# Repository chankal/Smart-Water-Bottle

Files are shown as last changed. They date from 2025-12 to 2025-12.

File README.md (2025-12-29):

# Smart-Water-Bottle
Water bottle attachment 

Hardware: 
- ESP32 s3 reverse feather with tft display
- MPU 6050
- DS3231 RTC
- HX711 Load Cell Amplifier + Load Cell Sensor

Proper hydration is important for many bodily functions and prevents dehydration which can lead to further complications. My smart bottle attachment can attach to any bottle and track hydration levels by keeping track of how often you drink water and how much water you drink. The user will be able to view this information on a web dashboard and tft display to clearly view their trends. Many people tend to forget about drinking water as it gets pushed to the back of their mind. I hope this device will allow people to be more mindful of staying hydrated

I originally experimented with using capacitance to read water level but later pivoted to using a load cell for more reliable results.

I made this project as part of CS 3651 Prototyping Intelligent Devices
[Project documentation (3).pdf](https://github.com/user-attachments/files/24356760/Project.documentation.3.pdf)

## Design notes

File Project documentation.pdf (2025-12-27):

## Smart Water Bottle Attachment Documentation:

Chandini Kalidindi

CS 3651

Goal/Motivation:

Proper hydration is important for many bodily functions and prevents dehydration which can lead to further complications. My smart bottle attachment can attach to any bottle and track hydration levels by keeping track of how often you drink water and how much water you drink. The user will be able to view this information on a dashboard to clearly see their trends. Many people tend to forget about drinking water as it gets pushed to the back of their mind. I hope this device will allow people to be more mindful of staying hydrated.

## Inputs:

For my microcontroller, I decided to use the ESP32-S3 with a tft display. This would allow the user to not have to charge the bottle as often since it uses less power than other microcontrollers and is able to do wifi connectivity so it can connect to my server to upload all drink information.

Weight(water level):
For my project, I needed a way to read water levels reliably over time. To do this I used a load cell which measures the weight of the water bottle. By calibrating to the empty weight and the full weight of the water bottle, I can correlate these values to the total capacity of water for the bottle. This means I will be able to measure how much water is in the bottle based on the weight.

Accelerometer:
In order to determine when an actual drink happens, I use the mpu 6050 to measure the acceleration along the z axis to approximate the tilt. When most of the acceleration is along the z axis that means it is upright. When assembling my project, I made sure that the mpu 6050 was mounted upward.

RTC: I used the rtc to log the time of the drink events to give the user a proper timeline of their hydration levels.

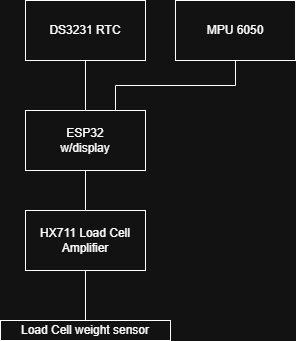
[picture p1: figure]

## Iterative Process:

Measuring Water Level:

For my project I originally wanted to use capacitance to measure water level by putting copper strips on the outside of the bottle. I originally tried using touchRead() to read capacitance but the values were too noisy and it was hard to measure any accurate values. I was able to get a slight linear relationship when pouring in water, but as soon as I moved the bottle slightly or brought my hand closer to the strips, it would mess up the values making it unusable.

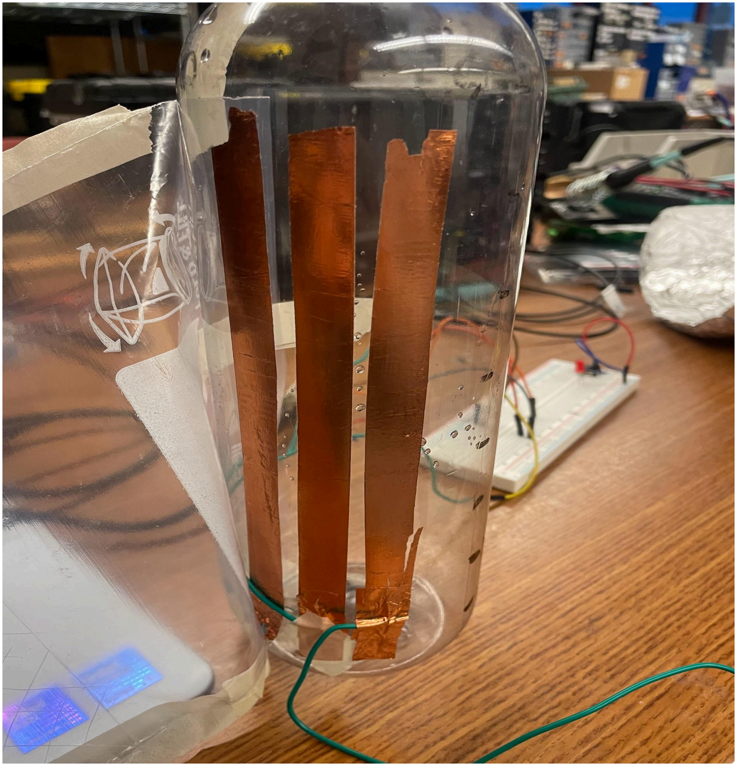
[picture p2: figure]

I also tried using a method similar to sd4 where I would take the amount of time it took the strips to charge based on the water level. The higher the water level, the longer the strips would charge before discharging. This method was a bit more promising after adding a grounded foil surrounding my bottle(not touching copper wires) and incorporating aggressive smoothing with the values. This method took a lot of experimenting with different resistor values to make the rc charging faster or slower. I also experimented with the size and placement of the copper strips. Overall after this process, I was able to detect changes in water level more reliably than my first method, but it still wasn’t reliable enough for long term measurements and the values would completely drift to different values. I believe this can be due to the changing humidity in the bottle and other environmental factors.

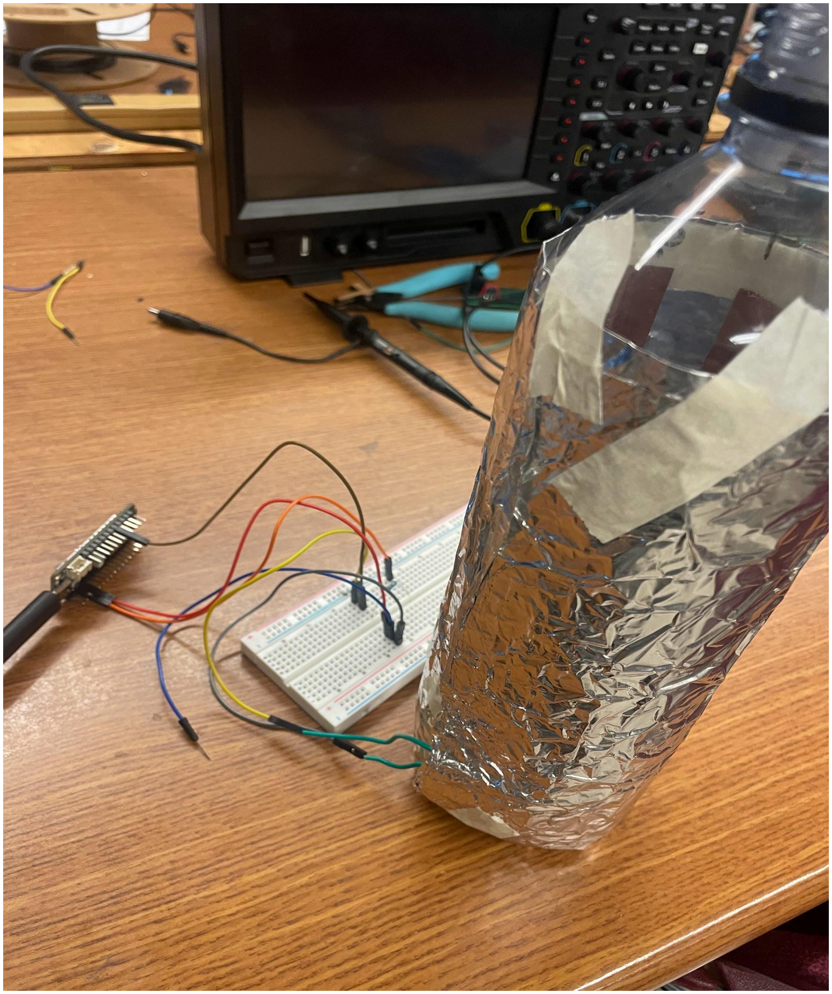
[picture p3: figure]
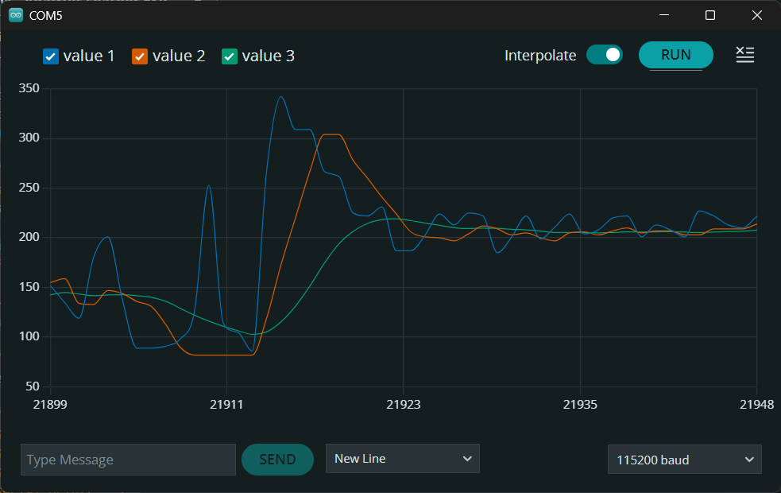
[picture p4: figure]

Overall, I concluded that using capacitance wouldn’t be a reliable way to measure water level for my project so I pivoted to my backup plan of using a load cell to measure weight which would be a much more reliable metric long term.

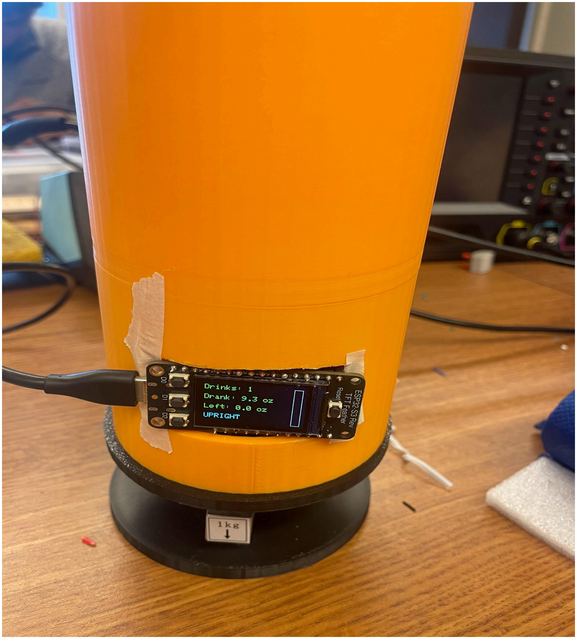
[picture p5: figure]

Outputs: For my outputs I used the tft display on the esp32. This allows me to stay more compact as I would not need additional hardware to mount on the outside of the bottle. On the tft display, the user can see how much water they have drank, how much they have left, and how many drinks they have to drink throughout the day. I also displayed this information on a hydration dashboard that the user can access to more easily view long term hydration information.

3D Printed Bottle Stand:

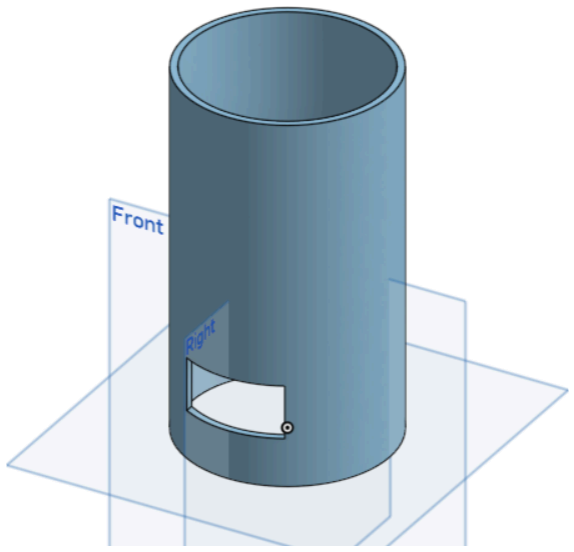
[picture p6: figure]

## Libraries:

Display:
Adafruit_GFX: I used this library for drawing text and shapes on my tft display Adafruit_ST7789: TFT Display driver

Sensors:
Adafruit_MPU6050: For accelerometer and gyro data.
Adafruit_Sensor
HX711: Library to read data from the load cell amplifier adc. RTClib: Library to interface with rtc using datetime.

Communication/data:
WiFi.h: Handles connecting the esp32 to wifi. HTTPClient.h: sends http post requests to fastapi backend. Fastapi
Pydantic
Sqlite3
Datetime

Esp32:
Wire.h : Handles i2c communication for the mpu6050 and rtc. SPI.h: Handles communication for tft display

## Resources:

DIY Capacitive Water Level Sensor using ESP32 Touch Read function (https://www.youtube.com/watch?v=40TjjWLljaU)

Non-contact Capacitive Liquid Level Sensing using FDC1004 - (https://www.hackster.io/team-protocentral/non-contact-capacitive-liquid-level-sensing-using-fdc1004-9333c7) Hackster.io

GitHub - Infineon/mtb-example-psoc4-capsense-liquid-level-sensing (https://github.com/Infineon/mtb-example-psoc4-capsense-liquid-level-sensing)

Capacitive liquid level sensing and shielding using arduino - Other Hardware / Sensors -Arduino Forum (https://forum.arduino.cc/t/capacitive-liquid-level-sensing-and-shielding-using-arduino/585182)

Value I added:
- Most of the similar projects online used the touchread() method but it was done on a stationary tank of water instead of a mobile device like a water bottle. I also saw examples that utilized a designated capacitance to digital chips. I was not able to find these parts online and I wanted to measure capacitance manually like we did in sd4. I was able to experiment myself using my own conclusions and thought process while iterating through my project.

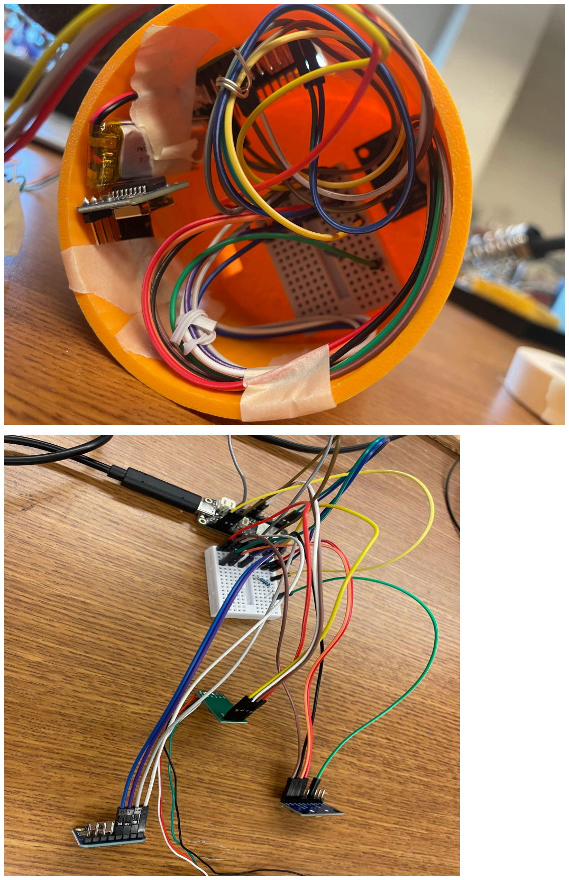
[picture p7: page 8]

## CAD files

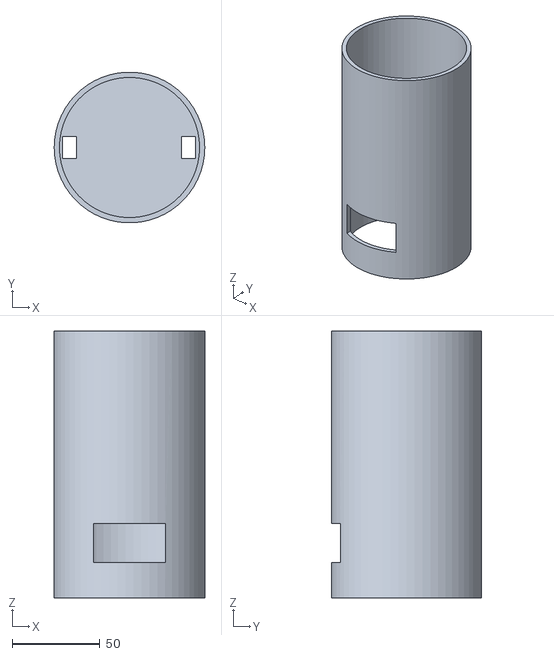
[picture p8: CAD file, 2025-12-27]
3d prints/Bottle Shell.stl
86.0 x 85.9 x 152.4

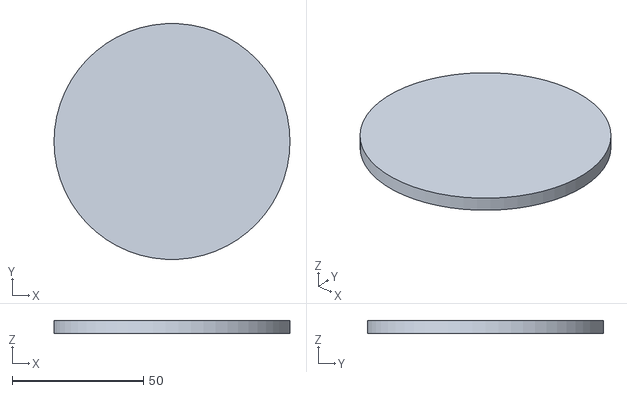
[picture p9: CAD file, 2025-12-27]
3d prints/Bottle Bottom.stl
90.0 x 89.9 x 5.00

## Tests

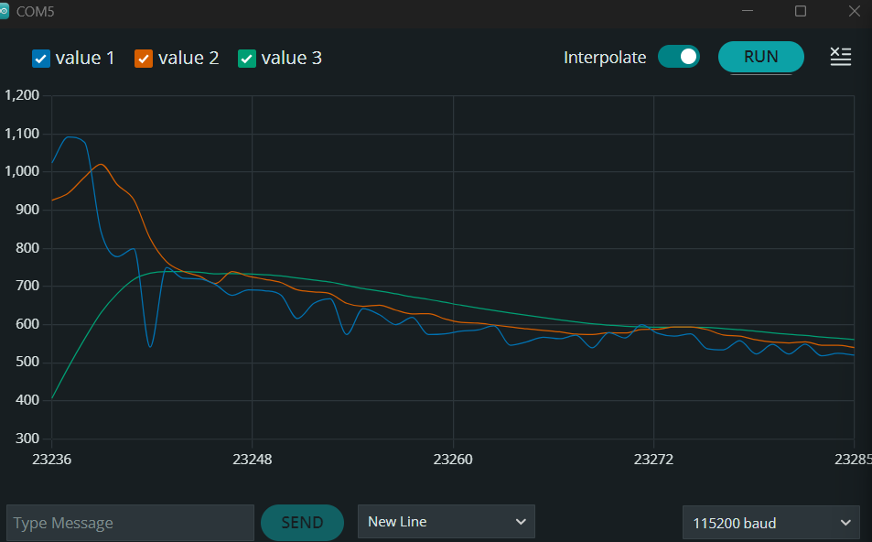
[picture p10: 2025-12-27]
Testing graphs/pour1.png

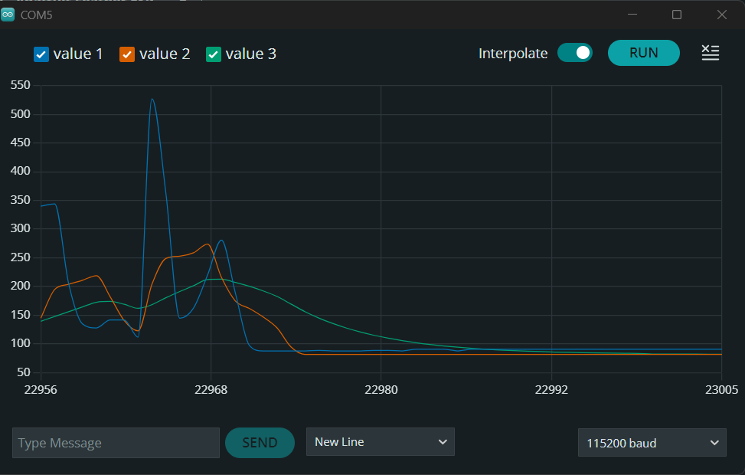
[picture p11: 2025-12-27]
Testing graphs/No water.png

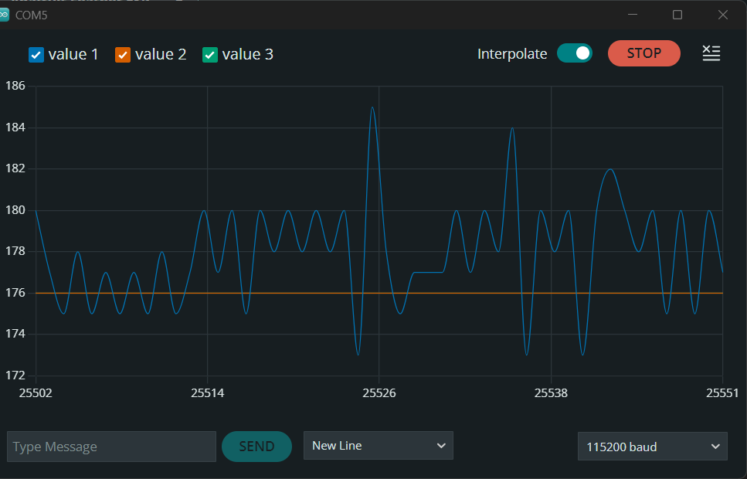
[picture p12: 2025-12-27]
Testing graphs/relatively stable.png

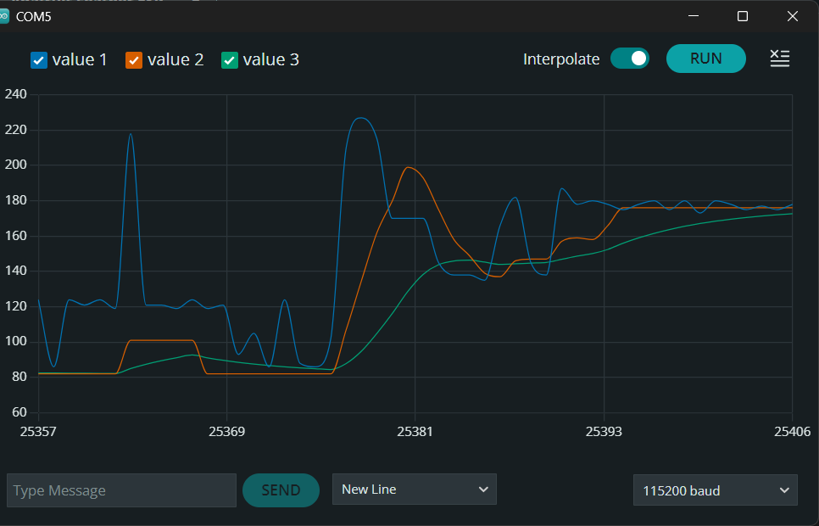
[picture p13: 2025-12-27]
Testing graphs/120_170_pour.png

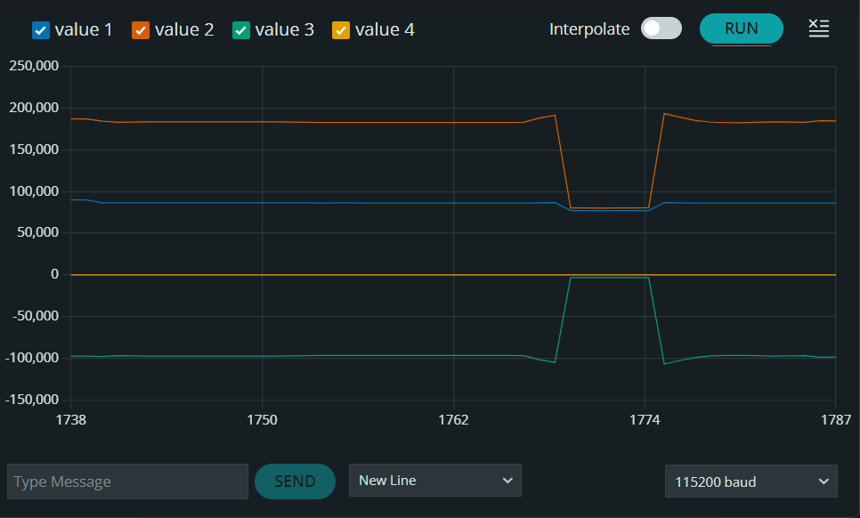
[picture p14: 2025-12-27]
Testing graphs/Grounding.png

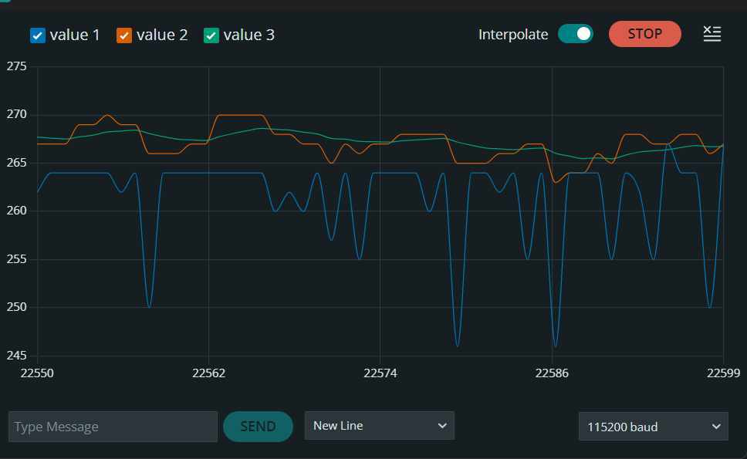
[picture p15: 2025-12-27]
Testing graphs/Screenshot 2025-11-30 214538.png

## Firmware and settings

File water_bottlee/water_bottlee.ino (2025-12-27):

#include <Wire.h>
#include <WiFi.h>
#include <HTTPClient.h>
#include <Adafruit_MPU6050.h>
#include <Adafruit_Sensor.h>
#include <RTClib.h>
#include "HX711.h"
#include <Adafruit_GFX.h>
#include <Adafruit_ST7789.h>
#include <SPI.h>


const char* ssid      = "";
const char* password  = "";
const char* serverUrl = "http://ip:8000/log_drink";


Adafruit_ST7789 tft = Adafruit_ST7789(TFT_CS, TFT_DC, TFT_RST);s

// pins
#define DT_PIN   12   // data
#define SCK_PIN  13   // clock


Adafruit_MPU6050 mpu;
RTC_DS3231 rtc;
HX711 scale;


const long EMPTY_WEIGHT = 453000; // // Calibration 350500, 107530
const long FULL_WEIGHT  = 2380500;
const long CAPACITY_DELTA = FULL_WEIGHT - EMPTY_WEIGHT; 
const float TOTAL_FL_OZ = 33.8;


float smoothedWeight = EMPTY_WEIGHT;
float alpha = 0.08;  // lower = smoother
uint32_t uprightStartTime = 0;
const uint32_t STABILIZE_TIME = 15000;

float totalDrankOz = 0;
float lastUprightWeight = FULL_WEIGHT;
int drinkCount = 0;

bool upright = true;
bool wasUpright = true;


#include <math.h>

bool isUpright(float az) {
  return (az > 5.5);
}



// ===== HTTP send helper =====
void sendDrinkEvent(float amount, int drinkNum, const char* rtcTime) {
  if (WiFi.status() != WL_CONNECTED) return;

  HTTPClient http;
  http.begin(serverUrl);
  http.addHeader("Content-Type", "application/json");

  String json = "{";
  json += "\"amountDrank\": " + String(amount, 2) + ",";
  json += "\"rtcTime\": \"" + String(rtcTime) + "\",";
  json += "\"drinkNumber\": " + String(drinkNum);
  json += "}";

  Serial.println("POSTing: " + json);
  int code = http.POST(json);
  Serial.printf("Server Response: %d\n", code);
  http.end();
}

void setup() {
  Serial.begin(115200);

  pinMode(TFT_BACKLITE, OUTPUT);
  digitalWrite(TFT_BACKLITE, HIGH);
  pinMode(TFT_I2C_POWER, OUTPUT);
  digitalWrite(TFT_I2C_POWER, HIGH);
  delay(20);

  tft.init(135, 240);
  tft.setRotation(3);
  tft.fillScreen(ST77XX_BLACK);

  Wire.begin();
  Wire.setClock(100000);
  rtc.begin();
  rtc.adjust(DateTime(F(__DATE__), F(__TIME__)));

  mpu.begin(0x69);
  mpu.setAccelerometerRange(MPU6050_RANGE_2_G);
  mpu.setFilterBandwidth(MPU6050_BAND_21_HZ);

  scale.begin(DT_PIN, SCK_PIN);

  Serial.println("Connecting WiFi...");
  WiFi.begin(ssid, password);
  while (WiFi.status() != WL_CONNECTED) {
    delay(500);
    Serial.print(".");
  }
  Serial.print("\nWiFi connected! IP: ");
  Serial.println(WiFi.localIP());

  Serial.println("\nSystem Ready!\n");
}

void loop() {
  DateTime now = rtc.now();

  // Accelerometer
  sensors_event_t a, g, temp;
  mpu.getEvent(&a, &g, &temp);
  upright = isUpright(a.acceleration.z);

  // Load Cell smoothing
  long rawW = scale.is_ready() ? scale.read() : smoothedWeight;
  smoothedWeight = alpha * rawW + (1 - alpha) * smoothedWeight;

  // Convert to ounces
  float currentOz = ((smoothedWeight - EMPTY_WEIGHT) / CAPACITY_DELTA) * TOTAL_FL_OZ;
  currentOz = constrain(currentOz, 0, TOTAL_FL_OZ);
  int percent = (currentOz / TOTAL_FL_OZ) * 100;

  // drinking logic
  static bool pendingDrink = false;

  if (!upright && wasUpright) {
    lastUprightWeight = smoothedWeight;
    pendingDrink = true;
  }

  if (upright && !wasUpright) {
    uprightStartTime = millis();
  }

  if (pendingDrink && upright) {
    if (millis() - uprightStartTime >= STABILIZE_TIME) {
      float change = (lastUprightWeight - smoothedWeight);
      float drinkOz = (change / CAPACITY_DELTA) * TOTAL_FL_OZ;

      if (drinkOz > 0.25) {  // Prevent accidental noise
        drinkCount++;
        totalDrankOz += drinkOz;

        char rtcStr[25];
        sprintf(rtcStr, "%04d-%02d-%02d %02d:%02d:%02d",
                now.year(), now.month(), now.day(),
                now.hour(), now.minute(), now.second());

        sendDrinkEvent(drinkOz, drinkCount, rtcStr);
        Serial.printf("DRINK %d: %.2f oz logged!\n", drinkCount, drinkOz);
      }

      pendingDrink = false;
    }
  }

  wasUpright = upright;
// display
  tft.fillRect(0, 0, 240, 135, ST77XX_BLACK);

  tft.setCursor(10, 10);
  tft.setTextSize(2);
  tft.setTextColor(ST77XX_GREEN);
  tft.printf("Drinks: %d", drinkCount);

  tft.setCursor(10, 40);
  tft.printf("Drank: %.1f oz", totalDrankOz);

  tft.setCursor(10, 70);
  tft.printf("Left: %.1f oz", currentOz);

  tft.setCursor(10, 100);
  tft.setTextColor(upright ? ST77XX_CYAN : ST77XX_RED);
  tft.print(upright ? "UPRIGHT" : "TILTED");

  // Progress bar
  int barX = 210, barY = 10, barW = 20, barH = 115;
  tft.fillRect(barX, barY, barW, barH, ST77XX_BLACK);

  int fillH = map(percent, 0, 100, 0, barH);
  int fillY = barY + (barH - fillH);

  tft.fillRect(barX, fillY, barW, fillH, ST77XX_BLUE);
  tft.drawRect(barX, barY, barW, barH, ST77XX_WHITE);

  // Debug
  Serial.printf(
    "%02d:%02d:%02d | Raw=%ld | Oz=%.2f | Drinks=%d | Total=%.2f oz\n",
    now.hour(), now.minute(), now.second(),
    rawW, currentOz, drinkCount, totalDrankOz
  );

  delay(200);
}

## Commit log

2025-12-27 Added project files and documentation
    [Bottle Bottom.stl, Bottle Shell.stl]
2025-12-27 Added project files
    [Bottle Bottom.stl, Bottle Shell.stl]
